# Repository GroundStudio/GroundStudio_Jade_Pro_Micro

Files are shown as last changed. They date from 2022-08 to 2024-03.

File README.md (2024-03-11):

GroundStudio Jade Pro Micro
====================================
(https://ardushop.ro/ro/home/1731-jade-pro-micro.html)

Get it from [ardushop.ro](https://ardushop.ro/ro/home/1731-jade-pro-micro.html)

Explore all the GroundStudio products at [GroundStudio.ro](https://groundstudio.ro/)

Description
-------------------
ATMEGA32U4 based development board with 32kBytes of In-System Self-Programmable Flash program memory, 1kBytes EEPROM, 2.5kBytes Internal SRAM, 5 PWM Channels, 18 Digital Pins and 9 channel 10 bit ADC Pins.

Contents
-------------------

* [/Documentation](https://github.com/GroundStudio/GroundStudio_Jade_Pro_Micro/tree/main/Documentation) -- Pinout.
* [/Hardware](https://github.com/GroundStudio/GroundStudio_Jade_Pro_Micro/tree/main/Hardware) -- Schematics, layout.

Versions
-------------------
*(Not all tags shown)*

- [REV 0.1]

License
-------------------

This is released under the [Attribution-ShareAlike 4.0 International (CC BY-SA 4.0)](https://creativecommons.org/licenses/by-sa/4.0/) license.
**You are welcome to use this for commercial purposes.**

Please consider contributing back to this project or others to help the open-source hardware community continue to thrive and grow! 

Certifications:

[Open Source Hardware Association](https://certification.oshwa.org/ro000004.html)   
   
certification-mark-RO000004-wide (https://certification.oshwa.org/ro000004.html)

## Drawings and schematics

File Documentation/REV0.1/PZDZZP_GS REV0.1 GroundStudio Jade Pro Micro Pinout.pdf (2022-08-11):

# GroundStudio Jade Pro Micro

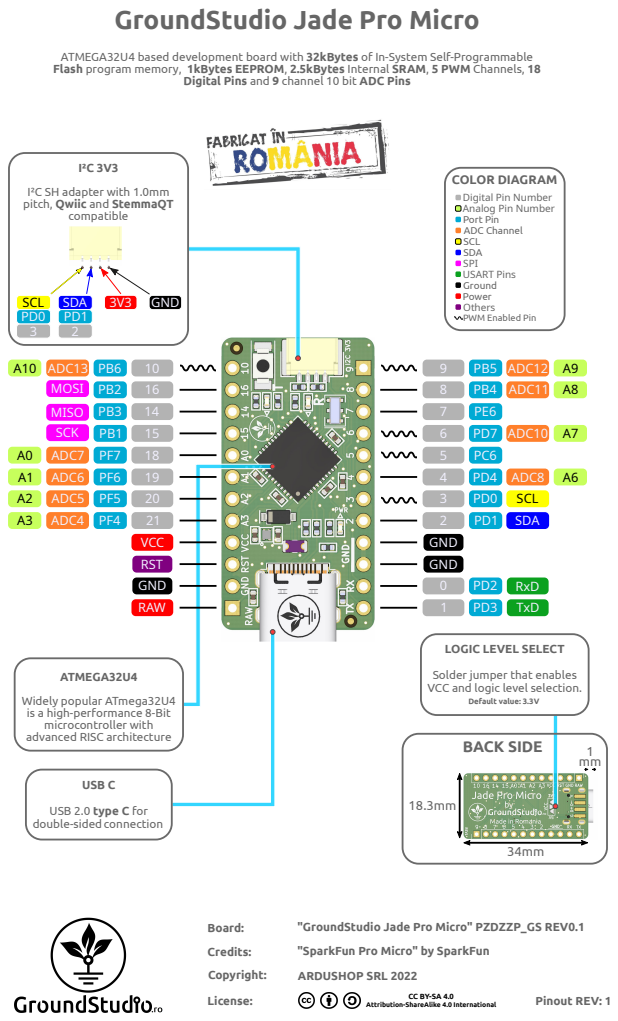
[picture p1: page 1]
VCC; RAW; RST GND; ADC7 ADC6 ADC5; A3 ADC4 PF4; SDA; SCL; TxD; RxD; GND; ADC8; ADC10; ADC11; ADC13; ADC12; SCK; MISO; MOSI; I²C 3V3; compatible; SCL SDA; 3V3 GND; USB C; advanced RISC architecture; BACK SIDE; Default value: 3.3V; Copyright:; License:; ARDUSHOP SRL 2022; Pinout REV: 1; Board:; "GroundStudio Jade Pro Micro" PZDZZP_GS REV0.1; Credits:; "SparkFun Pro Micro" by SparkFun

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

Digital Pins and 9 channel 10 bit ADC Pins

COLOR DIAGRAM
Digital Pin Number
Analog Pin Number
Port Pin
ADC Channel
SCL
SDA
SPI
USART Pins
Ground
Power
Others
PWM Enabled Pin

I²C SH adapter with 1.0mm
pitch, Qwiic and StemmaQT

LOGIC LEVEL SELECT

Solder jumper that enables
VCC and logic level selection.

ATMEGA32U4
Widely popular ATmega32U4
is a high-performance 8-Bit
microcontroller with

USB 2.0 type C for
double-sided connection

Attribution-ShareAlike 4.0 International

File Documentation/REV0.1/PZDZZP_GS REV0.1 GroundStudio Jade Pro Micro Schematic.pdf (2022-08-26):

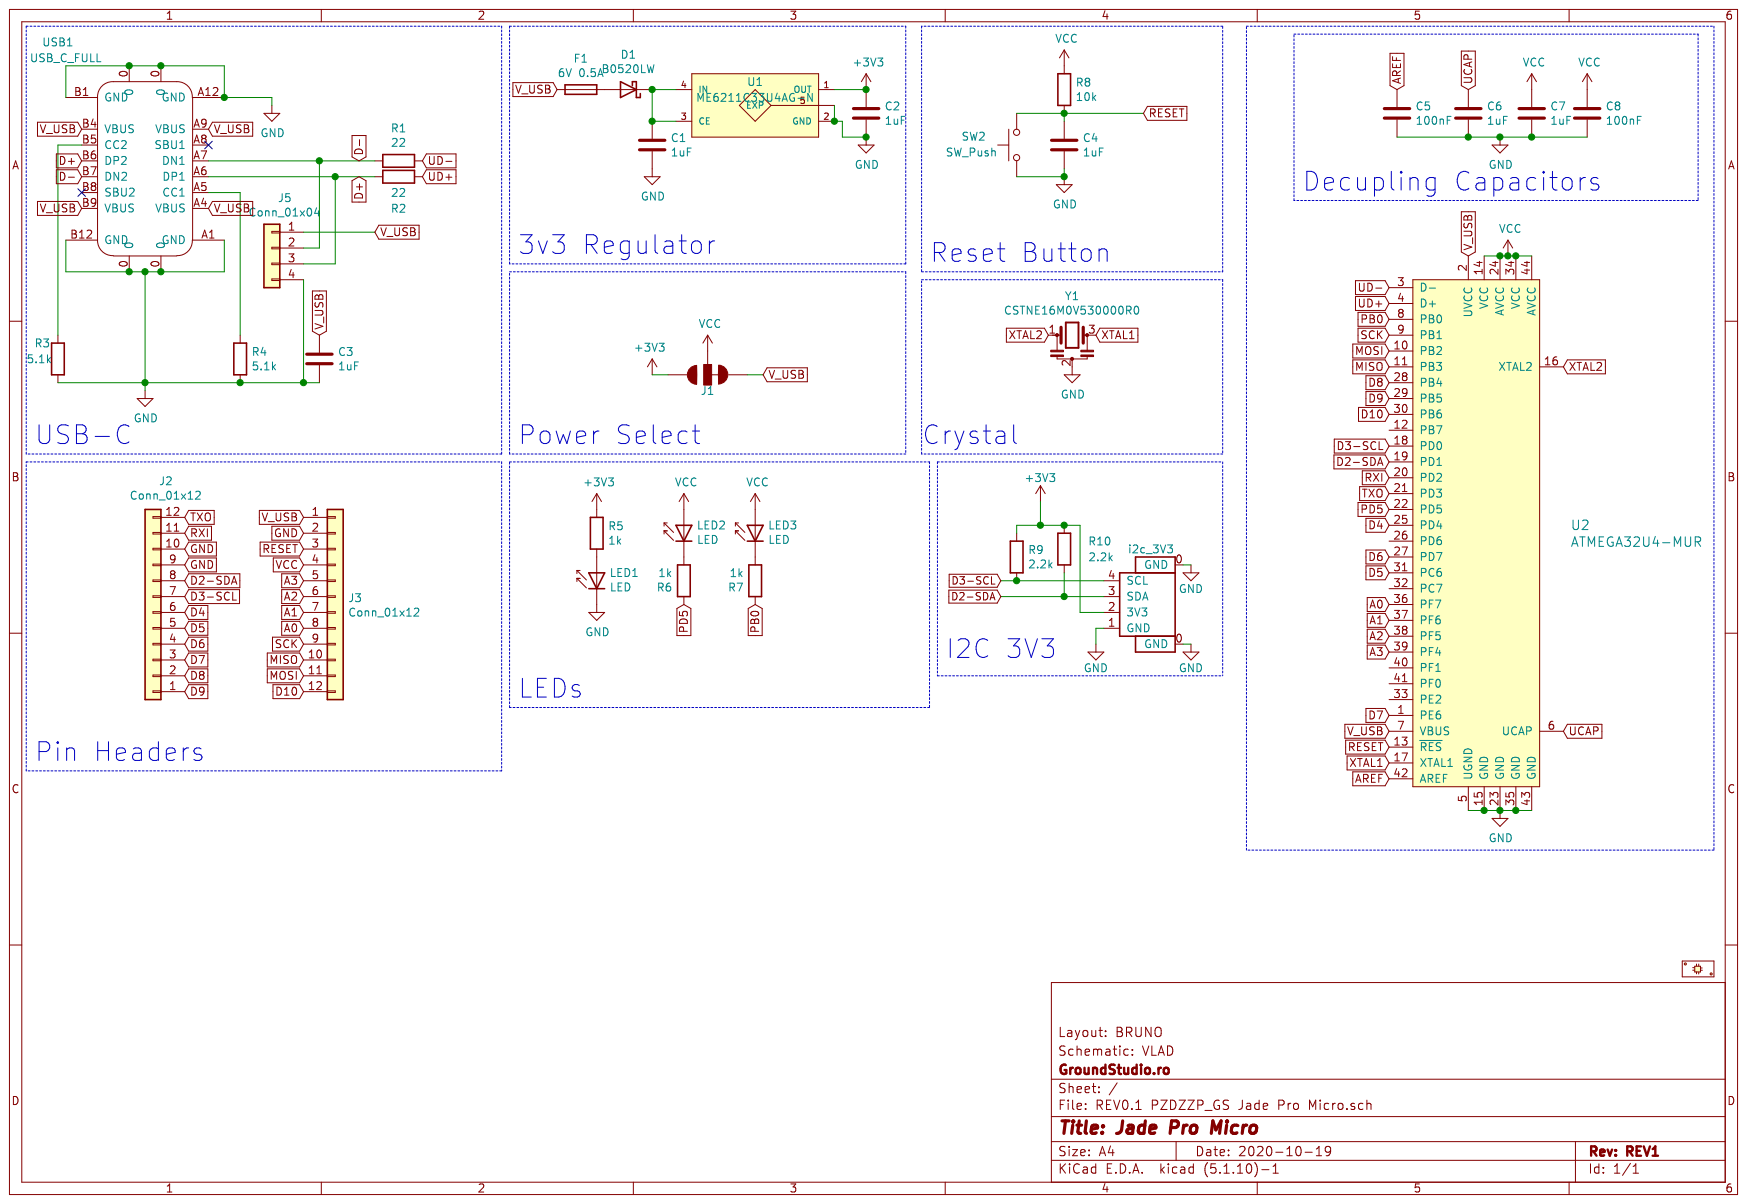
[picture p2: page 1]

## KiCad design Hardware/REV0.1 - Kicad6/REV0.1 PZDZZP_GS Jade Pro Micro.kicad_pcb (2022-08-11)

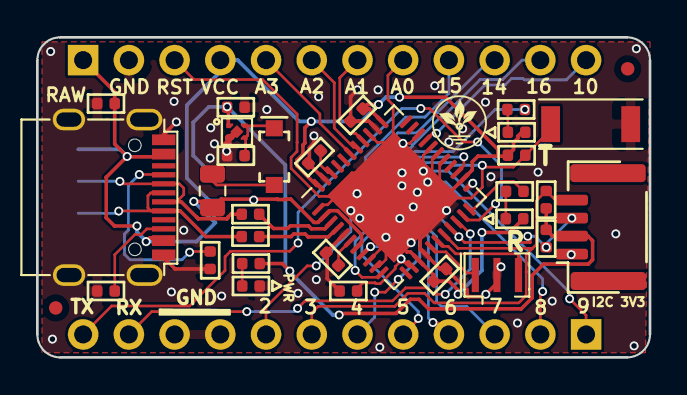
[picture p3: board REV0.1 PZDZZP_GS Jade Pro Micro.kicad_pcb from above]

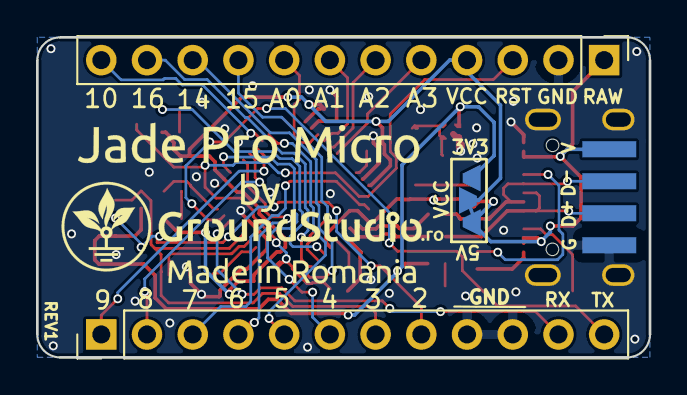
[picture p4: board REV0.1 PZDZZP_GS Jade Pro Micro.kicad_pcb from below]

Board: 2 copper layers, 34.0 x 17.8 mm, 33 parts (4 on the bottom side), 40 nets.

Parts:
C1, C2, C3, C4, C6, C7: 1uF; C_0402_1005Metric
C5, C8: 0.1uF; C_0402_1005Metric
D1: D_Schottky; SOD-123
F1: 6V 0.5A; Fuse_0805_2012Metric
J1: SolderJumper_DUAL_NC_1-3
J2, J3: Conn_01x12; PinHeader_1x12_P2.54mm_Vertical_Male
J5: Conn_01x04; USB-SOLDER-PADS
LED1, LED2, LED3: LED; LED_0402_1005Metric
R1, R2: 22; R_0402_1005Metric
R3, R4: 5.1k; R_0402_1005Metric
R5, R6, R7: 1k; R_0402_1005Metric
R8: 10k; R_0402_1005Metric
R9, R10: 2.2k; R_0402_1005Metric
SW2: SW_Push; TS342A2P-WZ
U1: ME6211C33U4AG-N; FBP1-1-4
U2: ATMEGA32U4-MUR; QFN-44-1EP_7x7mm_P0.5mm_EP5.15x5.15mm
USB1: USB_C_FULL; USB_C_C167321
X1: i2c_3V3; SH__1x04_P1.00mm_Horizontal
Y1: CSTNE16M0V530000R0; Resonator_SMD_muRata_CSTxExxG-3Pin_3.2x1.3mm

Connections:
+3V3: C2.1, J1.2, R5.1, R9.1, R10.1, U1.1, X1.2
A0: J3.8, U2.36
A1: J3.7, U2.37
A2: J3.6, U2.38
A3: J3.5, U2.39
AREF: C5.1, U2.42
D2-SDA: J2.8, R10.2, U2.19, X1.3
D3-SCL: J2.7, R9.2, U2.18, X1.4
D4: J2.6, U2.25
D5: J2.5, U2.31
D6: J2.4, U2.27
D7: J2.3, U2.1
D8: J2.2, U2.28
D9: J2.1, U2.29
D10: J3.12, U2.30
D+: J5.3, R2.2, USB1.A6, USB1.B6
D-: J5.2, R1.2, USB1.A7, USB1.B7
GND: C1.2, C2.2, C3.2, C4.2, C5.2, C6.2, C7.2, C8.2, J2.9, J2.10, J3.2, J5.4, LED1.1, R3.2, R4.2, SW2.1, U1.2, U1.5, U2.5, U2.15, U2.23, U2.35, U2.43, USB1.0, USB1.A1, USB1.A12, USB1.B1, USB1.B12, X1.1, Y1.2
MISO: J3.10, U2.11
MOSI: J3.11, U2.10
unnamed: C1.1, D1.1, U1.3, U1.4
unnamed: D1.2, F1.1
unnamed: LED1.2, R5.2
unnamed: LED2.1, R6.2
unnamed: LED3.1, R7.2
unnamed: R3.1, USB1.B5
unnamed: R4.1, USB1.A5
PB0: R7.1, U2.8
PD5: R6.1, U2.22
RESET: C4.1, J3.3, R8.2, SW2.2, U2.13
RXI: J2.11, U2.20
SCK: J3.9, U2.9
TXO: J2.12, U2.21
UCAP: C6.1, U2.6
UD+: R2.1, U2.4
UD-: R1.1, U2.3
VCC: C7.1, C8.1, J1.3, J3.4, LED2.2, LED3.2, R8.1, U2.14, U2.24, U2.34, U2.44
V_USB: C3.1, F1.2, J1.1, J3.1, J5.1, U2.2, U2.7, USB1.A4, USB1.A9, USB1.B4, USB1.B9
XTAL1: U2.17, Y1.3
XTAL2: U2.16, Y1.1

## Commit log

2022-08-11 - initial commit
    [REV0.1 PZDZZP_GS Jade Pro Micro.kicad_pcb, REV0.1 PZDZZP_GS Jade Pro Micro.kicad_sch]
2022-08-26 - added schematic pdf file
2022-08-26 - added "Kicad6" to revision folder name
    [REV0.1 PZDZZP_GS Jade Pro Micro.kicad_pcb, REV0.1 PZDZZP_GS Jade Pro Micro.kicad_sch]
